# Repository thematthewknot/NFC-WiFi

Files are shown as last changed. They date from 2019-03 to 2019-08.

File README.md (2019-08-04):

Here's the board

# What is NFC-WiFi?
It is a NFC reader with WiFi!  
This project joins a NFC reader(PN532) to a WeMos D1 Mini to allow for WiFi access.  
What can you do with this?
* Toggle a IFTTT event with a NFC tag
* Integrate into home automation systems
* Send notification when scanned
* And much more

# Getting started
Go check out the getting started [tutorials](https://www.mattvarian.com/nfc-wifi)

# Videos 
[Initial setup](https://youtu.be/GJwHEKRzi4o)

[Opening Front Door](https://www.youtube.com/watch?v=mKFkm8zK5ho)

# Where do I get one?

They are now for sale on my tindie: [Get yours here](https://www.tindie.com/products/thematthewknot/nfc-wifi-board/)

# Hardware used
* PN532 Board
* WeMos D1 Mini 4M
* custom PCB to join the two with addressable RGB LED
* 3D printed Enclosure

# Pinout Notes
## Led (APA102)
* data - 5
* clock - 4

## D1 Mini (WeMos 4M)
* sck - 16 
* miso - 14
* mosi - 12
* ss - 13

# Enclosure 
The enclosure is 1.8in x 1.85in x 0.8in(46mm x 47mm x 20mm) 3D printed with PETG so should hold up to outdoors to some extent however if it's going to be outdoors you'll want to seal up the hole where the USB connects.  

There are also some diviots to ease in mounting via screws, or you can use double sided tape to attach it to a surface.  

There is a lid that can slide off to allow you to remove the boards from inside. The hole is designed for the USB cable I send with board/enclosures when purchased but should fit most micro-USB cables.  
Enclosure

# Initial setup links

[IFTTT webhooks](https://ifttt.com/maker_webhooks)
Click Connect
Then Click Documentation to get your key

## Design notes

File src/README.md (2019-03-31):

# Notes
Use the following:
Board: LOLIN(WEMOS) D1 R2 & mini
Upload Speed: "921600"
CPU Frequency: "160 MHz"
Flash Size "4M (1M SPIFFS)"
lWIP Variant:(v1.4 Higher Bandwidth)

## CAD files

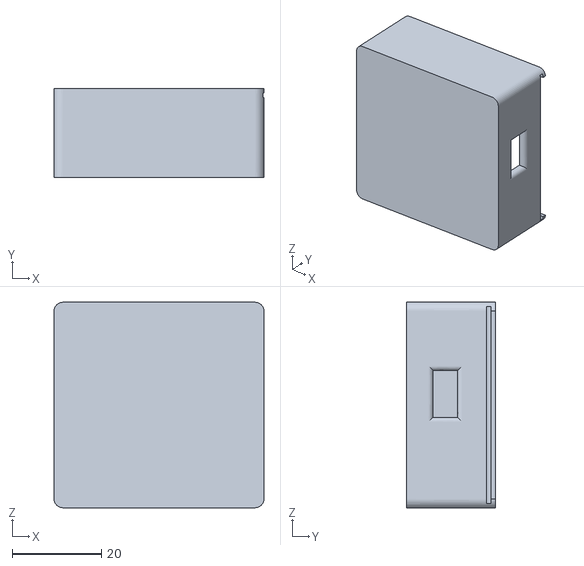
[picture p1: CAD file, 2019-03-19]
Hardware/Enclosure/Base.stl
47.0 x 20.0 x 46.0

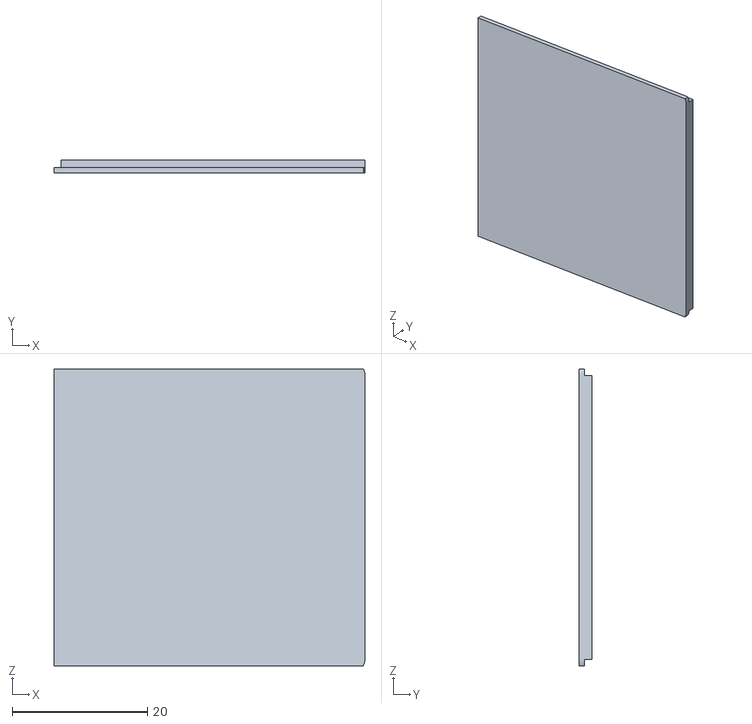
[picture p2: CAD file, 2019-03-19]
Hardware/Enclosure/Lid.stl
46.0 x 1.95 x 43.9

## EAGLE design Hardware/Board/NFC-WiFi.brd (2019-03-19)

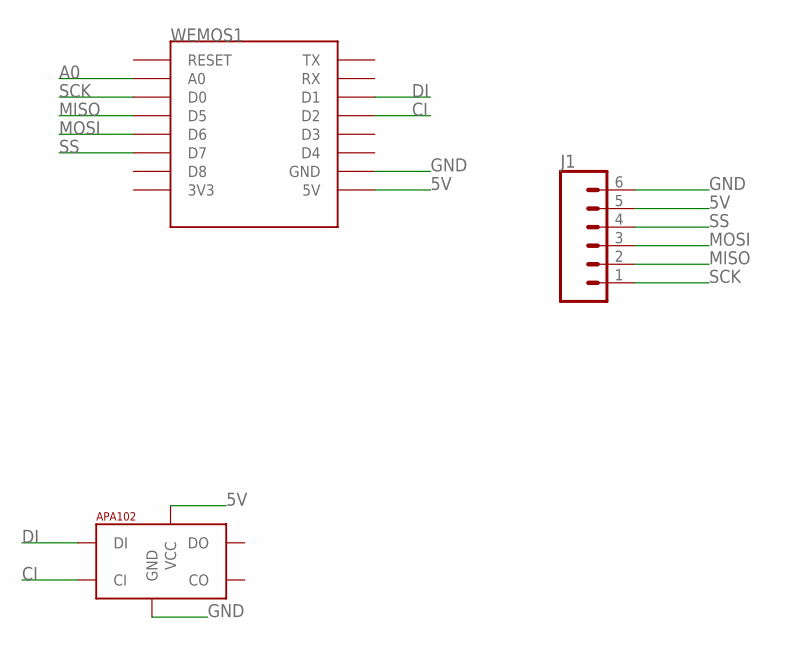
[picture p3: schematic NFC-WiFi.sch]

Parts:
J1: CONN_06SILK_FEMALE_PTH; 1X06
U$1: APA1025050; APA102_5050
WEMOS1: WEMOS-D1-MINI

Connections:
5V: J1.5, U$1.1 (VCC), WEMOS1.5V
A0: WEMOS1.A0
CI: U$1.5 (CI), WEMOS1.D2
DI: U$1.4 (DI), WEMOS1.D1
GND: J1.6, U$1.6 (GND), WEMOS1.GND
MISO: J1.2, WEMOS1.D5
MOSI: J1.3, WEMOS1.D6
SCK: J1.1, WEMOS1.D0
SS: J1.4, WEMOS1.D7

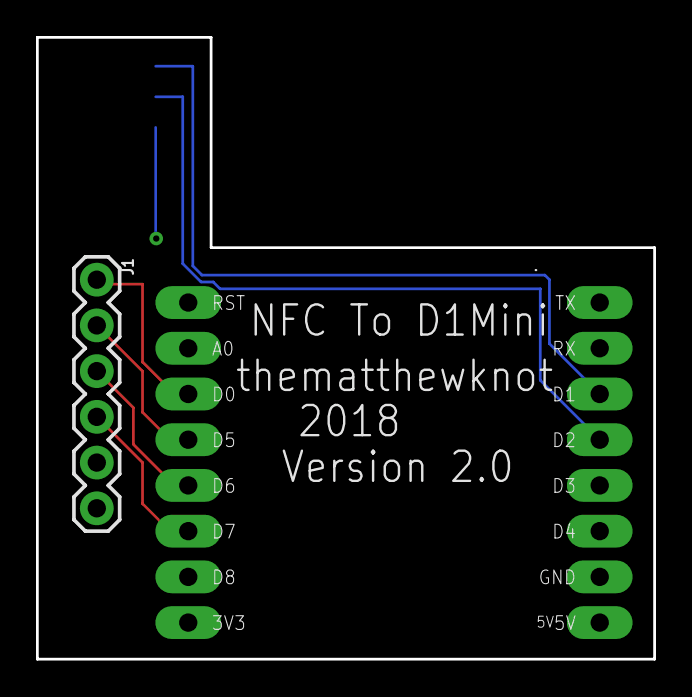
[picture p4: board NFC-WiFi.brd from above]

Board: 2 copper layers, 34.3 x 34.5 mm, 3 parts (1 on the bottom side), 8 nets.

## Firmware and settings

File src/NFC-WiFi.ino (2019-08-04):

// NFC-WiFi board simple program 2018 Matt Varian
// https://github.com/thematthewknot/NFC-WiFi
// released under the GPLv3 license.
//#include <FS.h>
#include <LittleFS.h>
#include <ESP8266WiFi.h> 
#include <ESP8266HTTPClient.h>
#include <WiFiManager.h>
#include <APA102.h>
#include <Adafruit_PN532.h>
#include <time.h>
#include <DNSServer.h>
#include <ESP8266WebServer.h>
#include <PubSubClient.h>

ESP8266WebServer server(80);
WiFiClient espClient;
PubSubClient mqttclient(espClient);

const uint8_t clockPin = 4;
const uint8_t dataPin = 5;

#define PN532_SCK  (16)
#define PN532_MOSI (12)
#define PN532_SS   (13)
#define PN532_MISO (14)
#define VERSION      3
#define MAXNUMTAGS  10 //Max number of tags


uint8_t uid[] = { 0, 0, 0, 0, 0, 0, 0 };

Adafruit_PN532 nfc(PN532_SCK, PN532_MISO, PN532_MOSI, PN532_SS);
APA102<dataPin, clockPin> ledStrip;

bool startScanning = false;
bool noClientConnected= true;
bool useMQTT = false;
int numTags; //default number of tags 
int timezone;


void spiffsWrite(String, String);
String host;
String IFTTTKey;
String storedTags[MAXNUMTAGS] = {};
String storedEvents[MAXNUMTAGS] = {};
String spiffsRead(String);
String MQTTbroker;
String MQTTtopic;
String MQTTport;
String MQTTuser;
String MQTTpass;
void LED_Off();
void LED_Blue();
void LED_Red();
void LED_Green();
void nfcread();
String UIDrecord();
void ToggleEvent(String);
void StoreTagsBeforeStart();
void send302(String);
void fetchURL(BearSSL::WiFiClientSecure, const char , const uint16_t, const char );

const char * header = R"(<!DOCTYPE html>
<html>
<head>
<title>NFC-WiFi</title>
<link rel="stylesheet" href="/style.css">
<meta name="viewport" content="width=device-width, initial-scale=1.0, maximum-scale=1.0, user-scalable=no" />
</head>
<body>
<div id="top">
  <span id="title">NFC-WiFi</span>
  <a href="/">Tags/Events</a>
  <a href="/setup">Setup</a>
  <a href="/debug">Debug</a>
</div>
)";

void setup()
{ 
  
  Serial.begin(115200);
  //SPIFFS.begin();
  LittleFS.begin();
  if ( ! LittleFS.exists("/useMQTT") ) {
    spiffsWrite("/useMQTT", "false");
  }
  if (spiffsRead("/useMQTT")=="true")
      useMQTT = true;   
  else
    useMQTT = false;   
  if ( ! LittleFS.exists("/uid1str") ) {
    spiffsWrite("/uid1str", "Not Set");
  }
  if ( ! LittleFS.exists("/event1str") ) {
    spiffsWrite("/event1str", "Not Set");
  }
  if ( ! LittleFS.exists("/numTags") ) {
    spiffsWrite("/numTags", String(1));
  }
  numTags = spiffsRead("/numTags").toInt();

  if( ! LittleFS.exists("/timezone")){
    spiffsWrite("/timezone", String(-4));
  }
  timezone = spiffsRead("/timezone").toInt();
  if( ! LittleFS.exists("/IFTTThost")){
    spiffsWrite("/IFTTThost", "maker.ifttt.com");
  }
  host = spiffsRead("/IFTTThost");
  if( ! LittleFS.exists("/IFTTTKEY")){
    spiffsWrite("/IFTTTKEY", "Not Set");
  }
  IFTTTKey = spiffsRead("/IFTTTKEY");

  nfc.begin();

  uint32_t versiondata = nfc.getFirmwareVersion();
  if (! versiondata) {
    Serial.print("Didn't find PN53x board");
    while (1); 
  }

  Serial.print("Found chip PN5"); Serial.println((versiondata>>24) & 0xFF, HEX);
  Serial.print("Firmware ver. "); Serial.print((versiondata>>16) & 0xFF, DEC);
  Serial.print('.'); Serial.println((versiondata>>8) & 0xFF, DEC);

  nfc.SAMConfig();
  LED_Yellow();

server.setContentLength(CONTENT_LENGTH_UNKNOWN);

server.on("/style.css", [&]() {
  server.send(200, "text/css", R"(
      html {
        font-family:sans-serif;
        background-color:black;
        color: #e0e0e0;
      }
      div {
        background-color: #202020;
      }
      h1,h2,h3,h4,h5 {
        color: #e02020;
      }
      a {
        color: #f05050;
        margin-left:12px;
      }
      form *, button {
        display:block;
        border: 1px solid #000;
        font-size: 14px;
        color: #fff;
        background: #444;
        padding: 5px;
        margin-bottom:12px;
      }
      #color-buttons {
        display:table;
        max-width:144px;
      }
      .color-button {
        width:36px;
        height:36px;
        display:inline;
        margin:0px !important;
      }
    )");
});
server.on("/", HTTP_GET,[&]() {

  server.sendHeader("Cache-Control", "no-cache, no-store, must-revalidate");
  server.sendHeader("Pragma", "no-cache");
  server.sendHeader("Expires", "-1");
  noClientConnected = false;
  String content = header;


  content += R"(
      </select>
      <!-- <button type="submit">Set</button> -->
      <form method="POST" id="Run" action="/RunScan">
        <button type="submit">RUN</button>
      </form>
      <p>Go to www.nfc-wifi.com for more info.</p>  
      <p>For first use click on Setup and go set your IFTTT webhook key.</p>
      <p>After you've set up the tags and events you wish to use hit run to start using the NFC-WiFi Board</p>
      <p>The board will automatically start running when powered up after 2min of no connection to the webpage</p>
 
      <form method="POST" id="useIFTTT" action="/useIFTTT">
        <button type="submit">Use IFTTT</button>
      </form>
      <form method="POST" id="useMQTT" action="/useMQTT">
        <button type="submit">Use MQTT</button>
      </form>
      
      )";


      
  if(!useMQTT){    
       content += R"(
      <h4>IFTTT Key</h4>
      <form method="POST" id="setup-device" action="/setup/IFTTTKEY">
        <input name="iftttkey" placeholder="IFTTTKey" value=")" + spiffsRead("/IFTTTKEY") + R"(">
        <button type="submit">Save</button>
      </form>  
      <p>Set The number of tags you want to use, then select set tag number</p>
      <form method="POST" id="SetTagNum" action="/setNumTags">
        <select name="numberOfTags">
          <option value="1">1</option>
          <option value="2">2</option>
          <option value="3">3</option>
          <option value="4">4</option>
          <option value="5">5</option>
          <option value="6">6</option>
          <option value="7">7</option>
          <option value="8">8</option>
          <option value="9">9</option>
          <option value="10">10</option>
        </select>
        <button type="submit">Set Tag Number</button>
      </form>
     <p>Click the register button and scan a tag once the scanner light goes blue.</p>
     <p>Once the light goes back to yellow refresh the page.</p>
  )";
  for(int i=1;i<numTags+1;i++)
  {
    content += R"(
     <h4>Tag )";
        content +=String(i);  
        content += R"(</h4>
      <form method='POST' id='UIDrec' action='/UIDrec'>
        <input name=")";
        content += String(i);
        content += R"(" placeholder="Not Set" value=")";
        content +=spiffsRead("/uid"+String(i)+"str");
        content += R"("">
        <button type='submit'>Register</button>
      </form>       
      )"; 
        
     content += R"(  
      <h4>Event )";
      content +=String(i);
       content += R"(</h4>
      <form method='POST' id='Eventrec' action='/Eventrec'>
        <input name=")";
                content += String(i);
         content += R"(" placeholder="Not Set" value=")";
        content +=spiffsRead("/event"+String(i));
         content += R"("">
        <button type='submit'>Save</button>
      </form>        
    )";
  }
  }
  else{
    content += R"(
                  <form method="POST" id="mqtt-address" action="/MQTT">

      <label>MQTT Broker Address</label>
        <input name="mqttbroker" placeholder="MQTTBroker" value=")" + spiffsRead("/MQTTBrokerAddress") + R"(">
        <br></br>
       <label>MQTT Port</label>
        <input name="mqttport" placeholder="1883" value=")" + spiffsRead("/MQTTport") + R"(">
              <br></br>

      <label>MQTT Topic</label>
        <input name="mqtttopic" placeholder="MQTTtopic" value=")" + spiffsRead("/MQTTtopic") + R"(">
                <br></br>
      <label>MQTT User</label>
        <input name="mqttuser" placeholder="MQTTuser" value=")" + spiffsRead("/MQTTuser") + R"(">
                   <br></br>
      <label>MQTT Password</label>
        <input name="mqttpass" placeholder="MQTTpass" value=")" + spiffsRead("/MQTTpass") + R"(">

        <button type="submit">Save MQTT info</button>
     
      </form>  

      
  )";
    
    
    
    }
  
  server.send(200, "text/html", content);
});
server.on("/MQTT", HTTP_POST, [&]() {
  spiffsWrite("/MQTTBrokerAddress", server.arg("mqttbroker"));
  if(!server.arg("mqttport"))
    spiffsWrite("/MQTTport", server.arg("1883"));
    
  else{
    spiffsWrite("/MQTTport", server.arg("mqttport"));
    MQTTpass = server.arg("MQTTpass");
  }
  spiffsWrite("/MQTTtopic", server.arg("mqtttopic"));
  spiffsWrite("/MQTTuser", server.arg("mqttuser"));
  spiffsWrite("/MQTTpass", server.arg("mqttpass"));
  send302("/");
});
server.on("/useMQTT", HTTP_POST, [&]() {
  spiffsWrite("/useMQTT", "true");
  useMQTT = true;
  Serial.println("Set to useMQTT");
  send302("/");
});

server.on("/useIFTTT", HTTP_POST, [&]() {
  spiffsWrite("/useMQTT", "false");
  useMQTT = false;
  Serial.println("Set to useIFTTT");
  send302("/");
});
server.on("/RunScan", HTTP_POST, [&]() {
   

  StoreTagsBeforeStart();

    Serial.println("endering run state");
});
server.on("/setNumTags", HTTP_POST, [&]() {

    String NumTagsStr = server.arg(0);
    numTags =NumTagsStr.toInt();
  spiffsWrite("/numTags",NumTagsStr);    
  send302("/");

    
});
server.on("/Eventrec", HTTP_POST, [&]() {
  String tempURLIndex = server.argName(0);

String EventStr =  server.arg(tempURLIndex);
 
  
  int EventIndex = tempURLIndex.toInt();
  Serial.println("event num:"+String(EventIndex));
  Serial.println("event is:"+EventStr);
  spiffsWrite("/event" + String(EventIndex), EventStr);
  send302("/");
});

server.on("/UIDrec", HTTP_POST, [&]() {
  String tempUIDIndex = server.argName(0);
  String tempstr = "";

  tempstr = UIDrecord();

  spiffsWrite("/uid" + tempUIDIndex + "str", tempstr);
  //send302("/");
  //server.sendHeader("Location", "/", true);
  //server.sendHeader("Location","/");
  //server.send(303);
  ESP.restart();
  //server.send ( 302, "text/plain", "/");
  
});



server.on("/setup", [&]() {
  server.setContentLength(CONTENT_LENGTH_UNKNOWN);
  server.sendHeader("Cache-Control", "no-cache, no-store, must-revalidate");
  server.sendHeader("Pragma", "no-cache");
  server.sendHeader("Expires", "-1");
  server.sendHeader("Content-Length", "-1");
  server.send(200, "text/html", header);

  server.sendContent("\
      <h1>Setup</h1>\
      <h4>Nearby networks</h4>\
      <table>\
      <tr><th>Name</th><th>Security</th><th>Signal</th></tr>\
    ");
  Serial.println("[httpd] scan start");
  int n = WiFi.scanNetworks();
  Serial.println("[httpd] scan done");
  for (int i = 0; i < n; i++) {
    server.sendContent(String() + "\r\n<tr onclick=\"document.getElementById('ssidinput').value=this.firstChild.firstChild.innerHTML; setTimeout(function(){ document.getElementById('pskinput').focus(); }, 100);\"><td><a href=\"#setup-wifi\">" + WiFi.SSID(i) + "</a></td><td>" + String((WiFi.encryptionType(i) == ENC_TYPE_NONE) ? "Open" : "Encrypted") + "</td><td>" + WiFi.RSSI(i) + "dBm</td></tr>");
  }
  server.sendContent(String() + "\
      </table>\
      <h4>Connect to a network</h4>\
      <form method='POST' id='setup-wifi' action='/setup/wifi'>\
        <input type='text' id='ssidinput' placeholder='network' value='" + String(WiFi.SSID()) + "' name='n'>\
        <input type='password' id='pskinput' placeholder='password' value='" + String(WiFi.psk()) + "' name='p'>\
        <button type='submit'>Save and Connect</button>\
      </form>\
    ");

  server.sendContent(String() + R"(
      <h4>Device Name</h4>
      <form method="POST" id="setup-device" action="/setup/device">
        <input name="name" placeholder="Device name" value=")" + spiffsRead("/name") + R"(">
        <button type="submit">Save</button>
      </form>
    )");

  server.sendContent(String() + R"(
      <h4>TimeZone</h4>
      <form method="POST" id="setup-device" action="/setup/timezone">
        <input name="tzname" placeholder="timezone" value=")" + spiffsRead("/timezone") + R"(">
        <button type="submit">Save</button>
      </form>
    )");
  server.client().stop();
});
server.on("/setup/timezone", HTTP_POST, [&]() {
  Serial.print("[httpd] timezone settings post. ");
  spiffsWrite("/timezone", server.arg("tzname"));
  timezone = spiffsRead("/timezone").toInt();
  send302("/setup?saved");
  Serial.println("done.");
});
server.on("/setup/IFTTTKEY", HTTP_POST, [&]() {
  Serial.print("[httpd] timezone settings post. ");
  spiffsWrite("/IFTTTKEY", server.arg("iftttkey"));
  IFTTTKey = spiffsRead("/IFTTTKEY");
  send302("/");
  Serial.println("done.");
});
server.on("/setup/device", HTTP_POST, [&]() {
  Serial.print("[httpd] Device settings post. ");
  spiffsWrite("/name", server.arg("name"));

  send302("/setup?saved");
  Serial.println("done.");
});
server.on("/debug", [&]() {
  String content = header;
  content += ("<h1>About</h1><ul>");

  unsigned long uptime = millis();
  content += (String("<li>Version ") + VERSION + "</li>");
  content += (String("<li>Booted about ") + (uptime / 60000) + " minutes ago (" + ESP.getResetReason() + ")</li>");
  content += ("</ul>");


  server.send(200, "text/html", content);
});

server.on("/version.json", [&]() {
  server.send(200, "text/html", String("1"));
  server.client().stop();
});
//  server.onNotFound ( handleNotFound );



WiFiManager wifiManager;
wifiManager.autoConnect("NFC_WiFi");
WiFi.hostname("NFC-WiFi");


server.begin(); // Web server start
Serial.println("End Of Setup Loop");


}




void loop() {

  if(noClientConnected) //timeout of 2min before starting to run if no one connects to website.
   { 
    if( millis()/120000) 
    {
      StoreTagsBeforeStart();   
    }
   }  


  if(startScanning){
    server.stop();
    nfcread();
  }
  else{
    server.handleClient();
    }
}

void StoreTagsBeforeStart(){ //read all thags and urls before starting 
  noClientConnected =false;
  startScanning = true;
  if(useMQTT){    
    MQTTbroker= spiffsRead("/MQTTBrokerAddress");
    MQTTport= spiffsRead("/MQTTport");
    MQTTtopic = spiffsRead("/MQTTtopic");
    MQTTuser = spiffsRead("/MQTTuser");
    MQTTpass = spiffsRead("/MQTTpass");

  }
  else{
  for(int i=0;i<numTags;i++)
  {      

      storedTags[i]=spiffsRead("/uid"+String(i+1)+"str");
      storedEvents[i]=spiffsRead("/event"+String(i+1));
  }
  }
  LED_Off();

  
}
void sendMQTTmessage(String UID)
{

 // LED_Green();


  mqttclient.setServer(MQTTbroker.c_str(), MQTTport.toInt());
  while(!mqttclient.connected())
  {
    
    mqttclient.connect("NFC-WiFi",MQTTuser.c_str(),MQTTpass.c_str());
    delay(1500);
  }

  mqttclient.publish(MQTTtopic.c_str(), UID.c_str());
 // LED_Off();
}
void nfcread(){
  server.stop();
  WiFi.mode(WIFI_STA);
  while(true){
  uint8_t success;
  uint8_t uid[] = { 0, 0, 0, 0, 0, 0, 0 };  // Buffer to store the returned UID
  uint8_t uidLength;              // Length of the UID (4 or 7 bytes depending on ISO14443A card type)
  
  
  success = nfc.readPassiveTargetID(PN532_MIFARE_ISO14443A, uid, &uidLength);
  
  if (success) {
    //Serial.println("Found an ISO14443A card");
    //Serial.print("  UID Length: ");    Serial.print(uidLength, DEC);   Serial.println(" bytes");
    //Serial.print("  UID Value: ");   
    //nfc.PrintHex(uid, uidLength);   
    //Serial.println("");
      if(!useMQTT){    
  
      String readuid = "";
      for(int i=0;i<uidLength;i++)
      {
        readuid = readuid + uid[i];
      }
      Serial.println(readuid);
     
      bool isMatch= false;
      for(int i=0;i<numTags;i++)
      {
          //Serial.println("DEBUG list:"+storedTags[i]);
         
          if(readuid==storedTags[i])
          {
              LED_Green();
             ToggleEvent(i);
            delay(5000);
             LED_Off();
             isMatch = true;
            break;
          }
                 
      }
        if(isMatch == false)
        {
          LED_Red();
          delay(3000);
          LED_Off();
        }
  
   
        
        }
        else
        {
          String readuid = "";
          for(int i=0;i<uidLength;i++)
          {
            readuid = readuid + uid[i];
          }
          Serial.println(readuid);
          LED_Green();
          sendMQTTmessage(readuid);
          delay(5000);
          LED_Off();
        }
        }
        
        
  }
}


String UIDrecord() {
  LED_Blue();
  uint8_t success;
  uint8_t uidLength;
  String tempstr = "";
  bool waitforread = true;
  while (waitforread) {
    success = nfc.readPassiveTargetID(PN532_MIFARE_ISO14443A, uid, &uidLength);

    if (success) {
      waitforread = false;
      //Serial.println("Found an ISO14443A card");
      //Serial.print("  UID Length: "); Serial.print(uidLength, DEC); Serial.println(" bytes");
     // Serial.print("  UID Value: ");
      //nfc.PrintHex(uid, uidLength);
      //Serial.println(" saving to UID slot: " + index_num);
      //Serial.println("*************");
      for (int i = 0; i < uidLength; i++)
        tempstr = tempstr + uid[i];
      //Serial.print("using index:");
     //Serial.println(index_num);
      
      
    }
  }
  LED_Off();
  //LED_Yellow();
  return tempstr;
  //delay(1);
}
void fetchURL(BearSSL::WiFiClientSecure *client, const char *host, const uint16_t port, const char *path) {
  if (!path) {
    path = "/";
  }

  ESP.resetFreeContStack();
  uint32_t freeStackStart = ESP.getFreeContStack();
  Serial.printf("Trying: %s:443...", host);
  client->connect(host, port);
  if (!client->connected()) {
    Serial.printf("*** Can't connect. ***\n-------\n");
    return;
  }
  Serial.printf("Connected!\n-------\n");
  client->write("GET ");
  client->write(path);
  client->write(" HTTP/1.0\r\nHost: ");
  client->write(host);
  client->write("\r\nUser-Agent: ESP8266\r\n");
  client->write("\r\n");
  uint32_t to = millis() + 5000;
  if (client->connected()) {
    do {
      char tmp[32];
      memset(tmp, 0, 32);
      int rlen = client->read((uint8_t*)tmp, sizeof(tmp) - 1);
      yield();
      if (rlen < 0) {
        break;
      }
      // Only print out first line up to \r, then abort connection
      char *nl = strchr(tmp, '\r');
      if (nl) {
        *nl = 0;
        Serial.print(tmp);
        break;
      }
      Serial.print(tmp);
    } while (millis() < to);
  }
  client->stop();
  uint32_t freeStackEnd = ESP.getFreeContStack();
  Serial.printf("\nCONT stack used: %d\n-------\n\n", freeStackStart - freeStackEnd);
}



void ToggleEvent(int Event_index)
{
   String event = storedEvents[Event_index];
   

   Serial.println("Attempting to call:"+event);

      WiFi.mode(WIFI_STA);
 //WiFi.begin(ssid, pass);
   String url = "/trigger/"+event+"/with/key/"+IFTTTKey;
  

  BearSSL::WiFiClientSecure client;
  client.setInsecure();
  fetchURL(&client, host.c_str(), 443, url.c_str());
   
}


void spiffsWrite(String path, String contents) {
  //Serial.println("SPIFFS Path:" + path);
  //Serial.println("SPIFFS contents:" + contents);
  File f = LittleFS.open(path, "w");
  f.print(contents);
  f.close();
}
String spiffsRead(String path) {
  //Serial.println("reading:" + path);
  File f = LittleFS.open(path, "r");
  String x = f.readStringUntil('\n');
  f.close();
  return x;
}

void LED_Blue()
{
  ledStrip.startFrame();
  ledStrip.sendColor(0, 0, 255, 1);
  ledStrip.endFrame(1);
}
void LED_Green()
{
  ledStrip.startFrame();
  ledStrip.sendColor(0, 255, 0, 1);
  ledStrip.endFrame(1);
}
void LED_Red()
{
  ledStrip.startFrame();
  ledStrip.sendColor(255, 0, 0, 1);
  ledStrip.endFrame(1);
}
void LED_Yellow()
{
  ledStrip.startFrame();
  ledStrip.sendColor(255, 255, 0, 1);
  ledStrip.endFrame(1);
}
void LED_Off()
{
  ledStrip.startFrame();
  ledStrip.sendColor(0, 0, 0, 1);
  ledStrip.endFrame(1);
}
void send302(String dest) {
  server.sendHeader("Location", dest, true);
  server.send ( 302, "text/plain", "");
  server.client().stop();
}
void setClock() {
  configTime(timezone * 3600, 0, "pool.ntp.org", "time.nist.gov");
  Serial.print("Waiting for NTP time sync: ");
  time_t now = time(nullptr);
  while (now < 8 * 3600 * 2) {
    delay(500);
    Serial.print(".");
    now = time(nullptr);
  }
  Serial.println("");
  struct tm timeinfo;
  gmtime_r(&now, &timeinfo);
  Serial.print("Current time: ");
  Serial.print(asctime(&timeinfo));
}

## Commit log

2019-03-19 Initial commit
    This code is just a basic program to test the LED and NFC , it does not yet integrate the WiFi.
2019-03-19 First commit
    These are the hardware files.
    [Base.stl, Lid.stl, NFC-WiFi.brd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]
2019-03-19 cleaned up pinout
    removed hardware pins to just have arduino pins
2019-03-21 Added enclosure info
    added photo of enclosure
2019-03-24 Not yet working`
    Not working at all, but getting closer wanted to commit before i misplaced this.
    [NFC-WiFi.ino]
2019-03-25 Fixed webpage
    Webpage now shows uid/url, also now tracks size of uid/url
    [NFC-WiFi.ino]
2019-03-28 working on fixing https
    still working on it
    [NFC-WiFi.ino]
2019-03-28 Fixed https
    Working now, uses SSL thanks to https://medium.com/@dfa_31434/doing-ssl-requests-on-esp8266-correctly-c1f60ad46f5e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
    [NFC-WiFi.ino]
2019-03-29 Fixed performance issue
    Fixed performance issue
    [NFC-WiFi.ino]
2019-03-30 https is broke
    no idea whats up, maybe my environment
    [NFC-WiFi.ino]
2019-03-30 fixed https
    Needed to go back to ESP8266WiFi v2.4.2 that fixed everything.
    [NFC-WiFi.ino]
2019-04-03 fixed http
    Added http handler to useURL
    [NFC-WiFi.ino]
2019-04-03 fixed http, also reads cert numbers
    [NFC-WiFi.ino]
2019-04-05 having random heap overflow issues with bearssl
    Not sure why, trying different ways to get it to play nice nothing working so far. Added a input for timezone to the setup page on the webpage.
    [NFC-WiFi.ino]
2019-04-05 fixed small thing
    cert file uploader
    [NFC-WiFi.ino]
2019-04-25 mqtt work
    added username/password/port to mqtt setup, turned led yellow when in webpage setup mode.
2019-08-04 Moved away from SPIFFS to LittleFS
    fixed a few issues, moved to use LittleFS
    [NFC-WiFi.ino]

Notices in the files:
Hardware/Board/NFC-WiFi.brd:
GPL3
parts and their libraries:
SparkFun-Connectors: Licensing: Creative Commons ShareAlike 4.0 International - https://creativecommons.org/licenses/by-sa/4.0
